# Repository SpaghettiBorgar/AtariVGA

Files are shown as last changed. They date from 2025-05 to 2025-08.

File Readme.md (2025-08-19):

# Atari to VGA Adapter
Converts VGA signals to the 13-pin DIN connector used by Atari SM/ST Series Monochrome CRT Monitors

## Features
- Adjustable R/G/B mixdown
- Adjustable output Attenuation/Amplification
- 3.5mm jack for audio passthrough
- VGA passthrough port
- 24C02 EEPROM for custom EDID
- Jumpers for SDA/SCL selection and write-protection
- Plenty of test-points for analyzing and debugging
- Blåhaj

> [!IMPORTANT]
> Some adapters will refuse to set a mode and send signals if it doesn't receive an EDID from the connected display. To provide an EDID you need to either connect a VGA monitor via the passthrough port or install and flash the 24C02 EEPROM with a valid EEPROM, preferably matching your monitor's specs as close as possible. Then use tools like `xrandr` to refine your VGA timings.

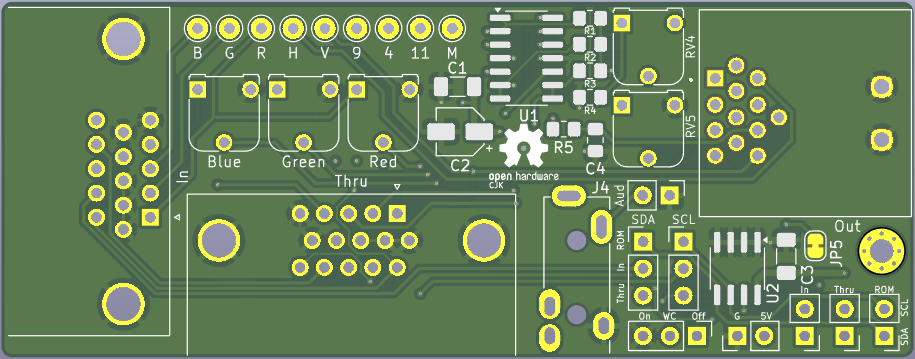
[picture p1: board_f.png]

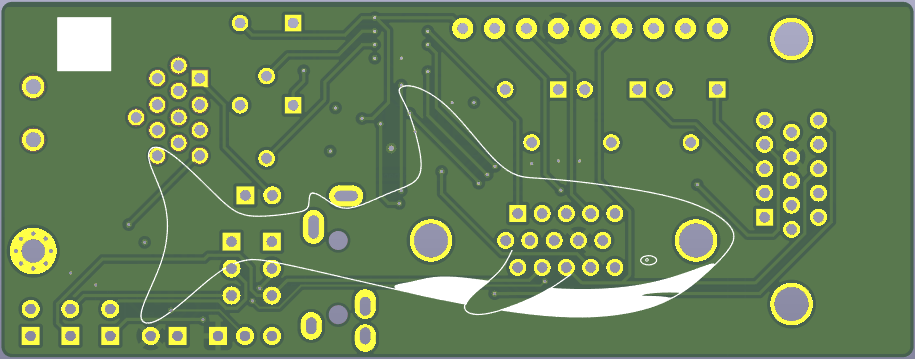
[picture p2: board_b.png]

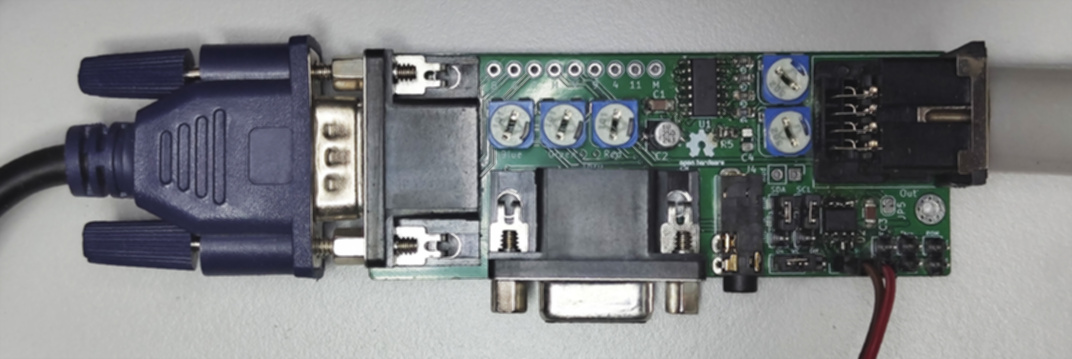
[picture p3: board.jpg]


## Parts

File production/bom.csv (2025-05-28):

Designator | Footprint | Quantity | Value | LCSC Part #
C1, C3 | 1206 | 2 | 100n
C2 | CP_Elec_4x5.4 | 1 | 10u
C4 | 0805 | 1 | C
J1, J2 | DSUB-15-HD_Socket_Horizontal_P2.29x2.54mm_EdgePinOffset8.35mm_Housed_MountingHolesOffset10.89mm | 2 | DE15_Socket_HighDensity_MountingHoles
J10, J11, J5, J8, J9 | PinHeader_1x02_P2.54mm_Vertical | 5 | Conn_01x02
J3 | CUI_SDF-130J | 1 | SDF-130J
J4 | Jack_3.5mm_CUI_SJ-3524-THT_Horizontal | 1 | AudioJack2
R1, R2, R3 | 0805 | 3 | 2.2k
R4 | 0805 | 1 | 3.3k
R5 | 0805 | 1 | R
RV1, RV2, RV3 | Potentiometer_Runtron_RM-065_Vertical | 3 | 100R
RV4, RV5 | Potentiometer_Runtron_RM-065_Vertical | 2 | 10k
TP1, TP2, TP3, TP4, TP5, TP6, TP7, TP8, TP9 | Pin_D1.0mm_L10.0mm | 9 | TestPoint
U1 | SOIC-14_3.9x8.7mm_P1.27mm | 1 | LM324
U2 | SOIC-8_3.9x4.9mm_P1.27mm | 1 | M24C02-FMN

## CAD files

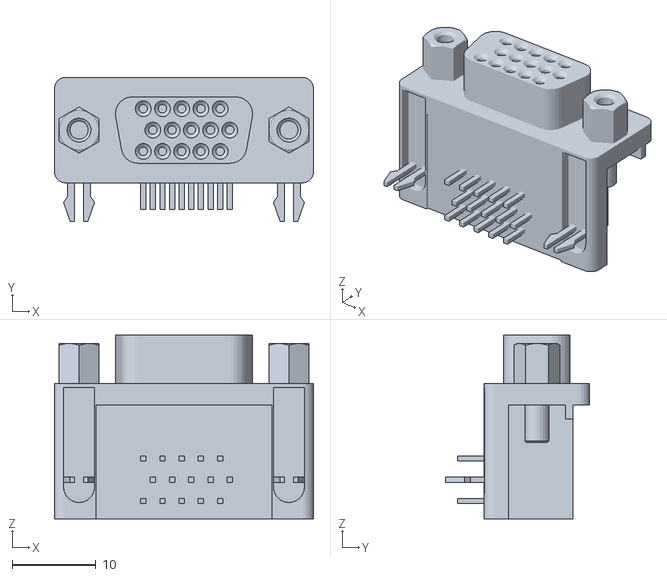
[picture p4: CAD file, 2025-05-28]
A-HDF_15_A-KG/161324383-53-a-hdf_15_a-kg_t/a-hdf_15_a-kg_t.obj
30.8 x 17.2 x 21.9

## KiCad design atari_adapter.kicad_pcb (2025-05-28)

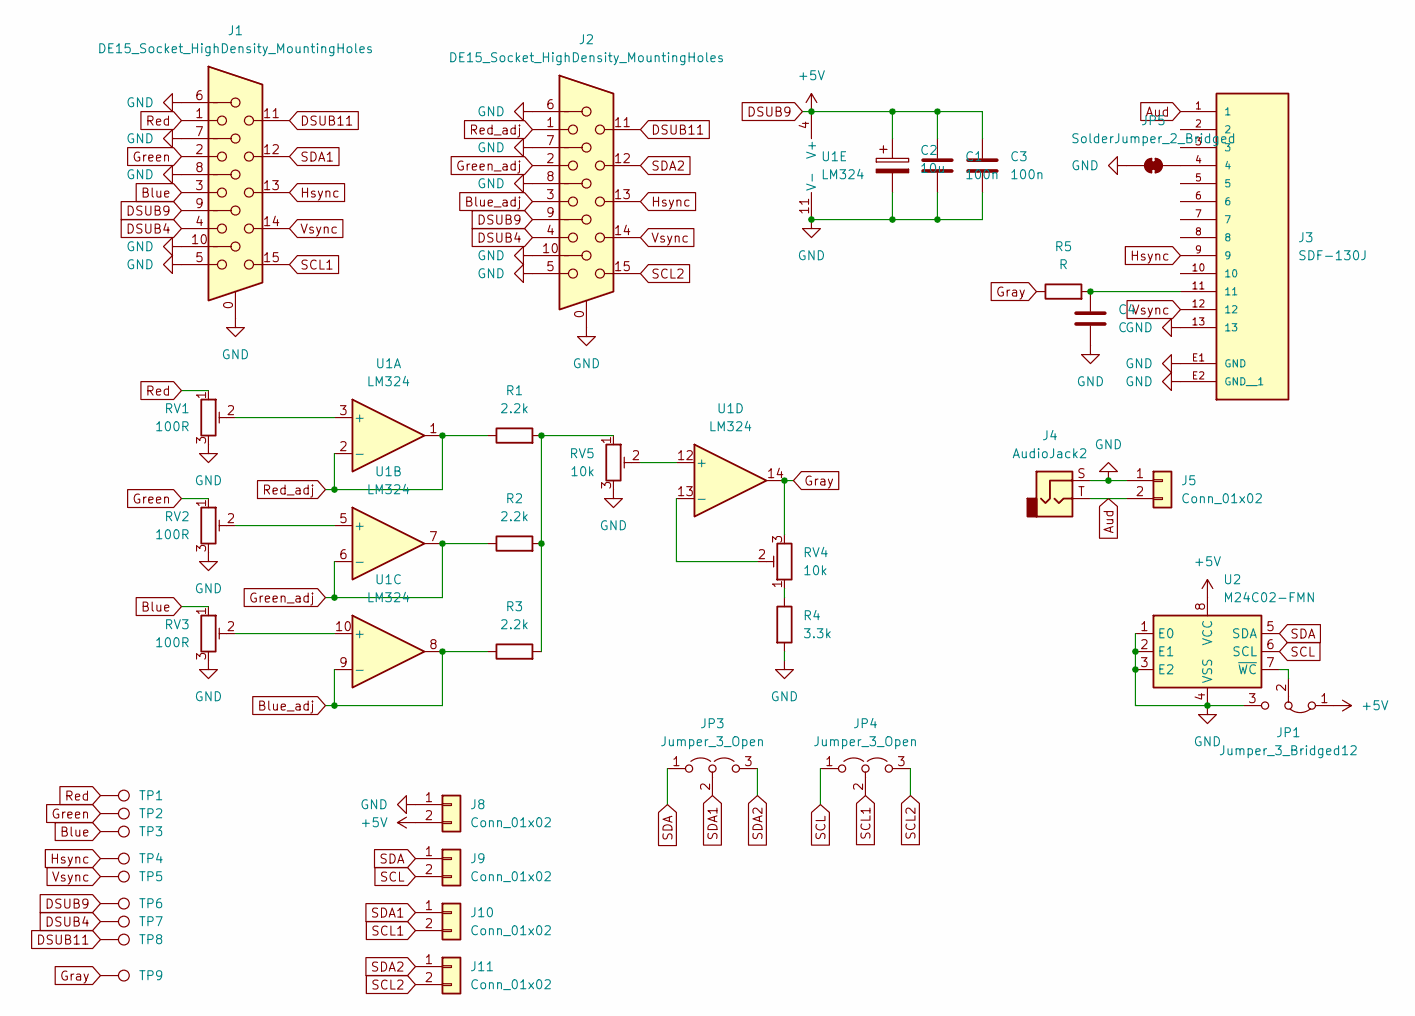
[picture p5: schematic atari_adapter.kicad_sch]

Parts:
C1, C3: 100n; C_1206_3216Metric_Pad1.33x1.80mm_HandSolder
C2: 10u; CP_Elec_4x5.4
C4: C; C_0805_2012Metric_Pad1.18x1.45mm_HandSolder
J1, J2: DE15_Socket_HighDensity_MountingHoles; DSUB-15-HD_Socket_Horizontal_P2.29x2.54mm_EdgePinOffset8.35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
J3: SDF-130J; CUI_SDF-130J; PARTREV 1.08/04-13-2020
J4: AudioJack2; Jack_3.5mm_CUI_SJ-3524-THT_Horizontal
J5, J8, J9, J10, J11: Conn_01x02; PinHeader_1x02_P2.54mm_Vertical
JP1: Jumper_3_Bridged12; PinHeader_1x03_P2.54mm_Vertical
JP3, JP4: Jumper_3_Open; PinHeader_1x03_P2.54mm_Vertical
JP5: SolderJumper_2_Bridged; SolderJumper-2_P1.3mm_Bridged_RoundedPad1.0x1.5mm
R1, R2, R3: 2.2k; R_0805_2012Metric_Pad1.20x1.40mm_HandSolder
R4: 3.3k; R_0805_2012Metric_Pad1.20x1.40mm_HandSolder
R5: R; R_0805_2012Metric_Pad1.20x1.40mm_HandSolder
RV1, RV2, RV3: 100R; Potentiometer_Runtron_RM-065_Vertical
RV4, RV5: 10k; Potentiometer_Runtron_RM-065_Vertical
TP1, TP2, TP3, TP4, TP5, TP6, TP7, TP8, TP9: TestPoint; Pin_D1.0mm_L10.0mm
U1: LM324; SOIC-14_3.9x8.7mm_P1.27mm
U2: M24C02-FMN; SOIC-8_3.9x4.9mm_P1.27mm

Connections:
Aud: J3.1, J4.T, J5.2
Blue: J1.3, RV3.1, TP3.1
Blue_adj: J2.3, R3.1, U1.8, U1.9 (-)
DSUB4: J1.4, J2.4, TP7.1
DSUB9: C1.1, C2.1, C3.1, J1.9, J2.9, J8.2, JP1.1 (A), TP6.1, U1.4 (V+), U2.8 (VCC)
DSUB11: J1.11, J2.11, TP8.1
GND: C1.2, C2.2, C3.2, C4.2, J1.0, J1.5, J1.6, J1.7, J1.8, J1.10, J2.0, J2.5, J2.6, J2.7, J2.8, J2.10, J3.13, J3.E1 (GND), J3.E2 (GND__1), J4.S, J5.1, J8.1, JP1.3 (B), JP5.1 (A), R4.2, RV1.3, RV2.3, RV3.3, RV5.3, U1.11 (V-), U2.1 (E0), U2.2 (E1), U2.3 (E2), U2.4 (VSS)
Gray: R5.1, RV4.3, TP9.1, U1.14
Green: J1.2, RV2.1, TP2.1
Green_adj: J2.2, R2.1, U1.6 (-), U1.7
Hsync: J1.13, J2.13, J3.9, TP4.1
unnamed: C4.1, J3.11, R5.2
unnamed: JP1.2 (C), U2.7 (~WC)
unnamed: J3.4, JP5.2 (B)
unnamed: R1.2, R2.2, R3.2, RV5.1
unnamed: R4.1, RV4.1
unnamed: RV1.2, U1.3 (+)
unnamed: RV2.2, U1.5 (+)
unnamed: RV3.2, U1.10 (+)
unnamed: RV5.2, U1.12 (+)
unnamed: RV4.2, U1.13 (-)
Red: J1.1, RV1.1, TP1.1
Red_adj: J2.1, R1.1, U1.1, U1.2 (-)
SCL: J9.2, JP4.1 (A), U2.6 (SCL)
SCL1: J1.15, J10.2, JP4.2 (C)
SCL2: J2.15, J11.2, JP4.3 (B)
SDA: J9.1, JP3.1 (A), U2.5 (SDA)
SDA1: J1.12, J10.1, JP3.2 (C)
SDA2: J2.12, J11.1, JP3.3 (B)
Vsync: J1.14, J2.14, J3.12, TP5.1

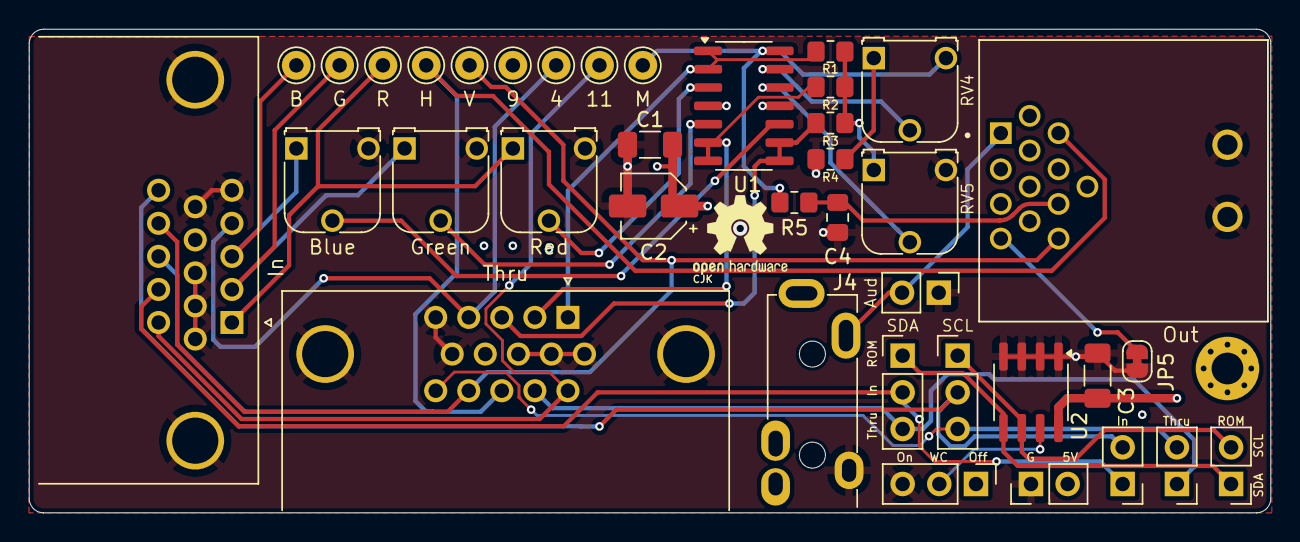
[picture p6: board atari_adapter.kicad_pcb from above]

Board: 4 copper layers, 86.0 x 33.5 mm, 38 parts (0 on the bottom side), 30 nets.

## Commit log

2025-05-28 Revision 1 completed
    [a-hdf_15_a-kg_t.obj, atari_adapter.kicad_pcb, atari_adapter.kicad_sch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]
2025-08-19 rm trash
    [atari_adapter.sync-conflict-20250423-225225-WH4ZBDF.kicad_pcb]
